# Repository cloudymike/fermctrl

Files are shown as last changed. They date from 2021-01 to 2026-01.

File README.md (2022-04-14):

# TempCtrl
Fermentation temperature controller

# Submodules
This repo includes submodules. After you have cloned, run:
`git submodule init`

# Install micropython on board
`cd tools
./reload.sh
`

# Install software on board

Make sure that you have created a config.py file in gcloudconfig.
If that file is not there, first go to gcloudconfig and follow the instructions
in the README.md file

`cd esp32
./RUN.sh
`

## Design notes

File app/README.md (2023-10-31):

# The app

## Run with flask and mqtt app separate
You need to start both scripts:
* runweb.sh (the flask app)
* runmqtt.sh (the mqtt reader and writer)
* runprometheus.sh (Prometheus colector)

In addition a redis server and a mosquitto server needs to run on localhost

## Run with docker compose

Remove container images that are build. Save some basics like redis and base python
`dockerclean.sh`

Bring up docker environment with a rebuild. Note that you may need to remove images to get a
clean rebuild
`docker-compose up --build`

## Run in testing mode
runtesting.sh

This mode includes a local mosquitto that allows a self contained environment for testing
May be useful as real environment, but some more testing needed.

## Ports
* web server -> 8081 Internal 5000
* prometheus -> 9090
* redis -> Internal  6379
* mosquitto -> 1883

## Prometheus expressions

Find all metrics for a device:
`{device_name=~"testcooler"}   `

Find a metric (actual_temperature) for all devices:
`actual_temperature`

Show just temperatures (actual and target) for one device
`{__name__=~"(actual|target)_temperature", device_name=~"alecooler"} `

To average over time use something like:
`avg_over_time(heater_on{device_name="testcooler"}[10m])`

We are starting to get into hacks here, and a better solution may be to use grafana

## Basic flask app on app engine.
This is obsolete as GOOGLE stopped their IOT mqtt offering

You may have to login to your google account
`gcloud auth login`

This is the google tutorial:
https://cloud.google.com/appengine/docs/standard/python3/quickstart

This is a very useful companion page that lists the gcloud commands that are useful to set things up:
https://medium.com/@dmahugh_70618/deploying-a-flask-app-to-google-app-engine-faa883b5ffab

### Setup service account credentials
export GOOGLE_APPLICATION_CREDENTIALS=~/secrets/gcloud/myproject.json
See https://cloud.google.com/pubsub/docs/building-pubsub-messaging-system#create_service_account_credentials

### Remove projects is a bad thing
They will be in delete mode for 30 days so during that time you can not add other projects. To see what you have in delete mode:

gcloud projects list --filter='lifecycleState:DELETE_REQUESTED'

### Read the logs of a appengine
gcloud app logs tail --project phrasal-talon-439

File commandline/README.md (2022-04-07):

# Commandline to control device

Source setup.sh  to setup virtual environment and include required packages.
Then run each file as a command

## Setup service account credentials
export GOOGLE_APPLICATION_CREDENTIALS=~/secrets/gcloud/myproject.json
See https://cloud.google.com/pubsub/docs/building-pubsub-messaging-system#create_service_account_credentials

## Initial command line with python

### command.py
Will send a command to the device. Currently the only command is the temperature to set.
Example:
```
./command.py 68
```

### subscribe.py
Will get all metrics from device, and try to clean queue
```
# ./subscriber.py
Listening for messages on projects/tempctrlproj/subscriptions/ferm1topic..

Received Message {
  data: b'{"temperature":80.6}'
  ordering_key: ''
  attributes: {
    "deviceId": "esp32tempctrl",
    "deviceNumId": "2577321808646966",
    "deviceRegistryId": "tempctrl",
    "deviceRegistryLocation": "us-central1",
    "projectId": "tempctrlproj",
    "subFolder": ""
  }
}.
```

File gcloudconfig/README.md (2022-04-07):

# Setting up gcloud

## Login
Start with logging in to your account
`gcloud auth login`

This will open a browser to login to your account.

After the login try to run a gcloud command, as example try to check the projects:
`gcloud projects list`

## Variables
Copy the variables.example.sh to variables.sh and update with the values
that matches your setup. If you are starting from scratch, you can probably use variables as
is. If you already have a project started use that project_id. To check if you have a project run
the command:
`gcloud projects list`

## Create a project
If you do not have a ready to go project create this next. Right now we create an app for each project, the
URL is
`https://PROJECT_ID.appspot.com`

Creating a lot of new project id's is a bad things as it takes 30 days to remove them.

To create project use
`./create_project.sh`

To delete a project (though it will take 30 days to happen..):
`./delete_project.sh`

# Create an app
Currently the app is a simple creation of one app per project. Use the following command:
`./create_app.sh`
To delete an app:
`./delete_app.sh`

# Create a device
This setups device and device registry with key and creates a config file that will be used
by app and esp32 board. Among other things this will generate the keypair to be  used
by mqtt to allow esp32 board and google app to communicate.

To create device use
`./create_device.sh`

To delete device use
`./delete_device.sh`

Note that this script also creates topics and subscriptions. These are kind of the same thing in mqtt but
not in gcloud. Note that a subscription expire after EXPIRATION_PERIOD, set to max 365 days.

# config.py
You should now have a file config.py. This file will NOT be checked in with the repo, so you may want to copy
it to a safe place. This file will be used by both app engine build and esp32 build to
link the two together.

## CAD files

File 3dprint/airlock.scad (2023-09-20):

$fa = 1;
$fs = 0.4;


boxdepth = 10;
boxwidth = 22.5;
wallthickness = 1;
ringheight = 6;
braceoffset = 16;
tubediameter = 11;

module lid() {
  difference () {
    cube([boxwidth-2*wallthickness,boxdepth-1*wallthickness,2],center=true);
    translate([0,boxdepth/2-3.5,1]) cube([20.5,1.5,1],center=true); // slot
    translate([0,-boxdepth/2,0]) cube([boxwidth-2*wallthickness,7*wallthickness,2],center=true); //space for bow
  }
}

module topbox(
  boxwidth=boxwidth,
  boxdepth=boxdepth,
  wallthickness=wallthickness,
  tbheight = 17
  ) {
  difference () {
    cube([boxwidth,boxdepth,tbheight],center=true);
    translate([0,-1,6]) cube([boxwidth-2*wallthickness,boxdepth,10],center=true);
    cube([boxwidth-2*wallthickness,boxdepth-2*wallthickness,tbheight],center=true);
  }  
}
module cardslot (boxwidth=boxwidth,boxdepth=boxdepth,wallthickness=wallthickness, csheight=8) {
  difference () {
    cube([boxwidth,boxdepth,csheight],center=true);
    translate([0,boxdepth/2-3.5,0]) cube([boxwidth-2*wallthickness,1.5,csheight],center=true);
    cube([10,boxdepth-2*wallthickness,csheight],center=true);
  }  
}  

module compressionring(ringheight=ringheight,tubediam=11,ringwall=2) {
  difference() {
    cylinder(h=ringheight,d=tubediam+2*ringwall,center=true);
    cylinder(h=ringheight,d=tubediam,center=true);
    translate([0,-ringheight,0]) cube([1,3,ringheight],center=true);
    
  }
}


module prism(l, w, h) {
       polyhedron(points=[
               [0,0,h],           // 0    front top corner
               [-w,0,0],[w,0,0],   // 1, 2 front left & right bottom corners
               [0,l,h],           // 3    back top corner
               [-w,l,0],[w,l,0]    // 4, 5 back left & right bottom corners
       ], faces=[ // points for all faces must be ordered clockwise when looking in
               [0,2,1],    // top face
               [3,4,5],    // base face
               [0,1,4,3],  // h face
               [1,2,5,4],  // w face
               [0,3,5,2],  // hypotenuse face
       ]);
}

module bottombox(
  boxwidth=boxwidth,
  boxdepth=boxdepth,
  wallthickness=wallthickness,
  ringheight = ringheight, 
  braceoffset=braceoffset, 
  tubediam=tubediameter, 
  ringwall=2, 
  bboxh=13
  ) {
  
  difference () {
    cube([boxwidth,boxdepth,bboxh],center=true);
    cube([boxwidth-2*wallthickness,boxdepth-2*wallthickness,13],center=true);
    //Create a notch for the cable connector
    translate([0,-boxdepth/2+wallthickness,0]) cube([10,wallthickness,bboxh],center=true);
  }
  difference () {
    translate([0,-boxdepth/2,-bboxh/2]) rotate([90,0,0]) prism(ringheight, boxwidth/2, braceoffset*2);
    translate([0,-boxdepth/2-braceoffset,-bboxh/2]) cylinder(d=tubediam + ringwall*2, h=ringheight);
    // This is a little hackish, wanted to make the brace a little wider so needed to make it longer and cut off the tip
    translate([0,-boxdepth/2-braceoffset-tubediam,-bboxh/2+ringheight/2]) cube([braceoffset,braceoffset,ringheight],center=true);
  }
  translate([0,-boxdepth/2-braceoffset,-bboxh/2+ringheight/2]) compressionring(ringheight,tubediam,ringwall);
}

module sensorbox(
  boxwidth = boxwidth,
  boxdepth = boxdepth,
  wallthickness = wallthickness,
  ringheight = ringheight, 
  braceoffset=braceoffset, 
  tubediam=tubediameter, 
  ringwall=2
  ) {
    bboxh=13;
    csheight=8;
    tbheight = 18;
    bottombox(boxwidth,boxdepth,wallthickness,ringheight, braceoffset, tubediam, ringwall, bboxh);
    translate([0,0,bboxh/2+csheight/2]) cardslot(boxwidth,boxdepth,wallthickness,csheight);
    translate([0,0,bboxh/2+csheight+tbheight/2]) topbox(boxwidth,boxdepth,wallthickness,tbheight);
}
//bottombox();
//topbox();  
//cardslot(); 

sensorbox();
translate ([40,0,0])  lid();

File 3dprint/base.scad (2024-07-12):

use <scadexamples/electrocookie/baseplate.scad>
baseplate(
    board_version="full",
    bottom_holes=[19,20,21,24,25,26,40,42,61,63],
    top_holes=[40,42,58,60],
    power_connector=true
);

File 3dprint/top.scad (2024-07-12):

use <scadexamples/electrocookie/topbox.scad>
topbox(
    board_version="full",
    display_pin1_row = 23,
    jack_pin1_row = 0,
    ESP32_pin1_column = "B",
    power_connector=true
    );

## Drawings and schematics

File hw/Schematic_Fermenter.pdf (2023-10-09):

A | A

1

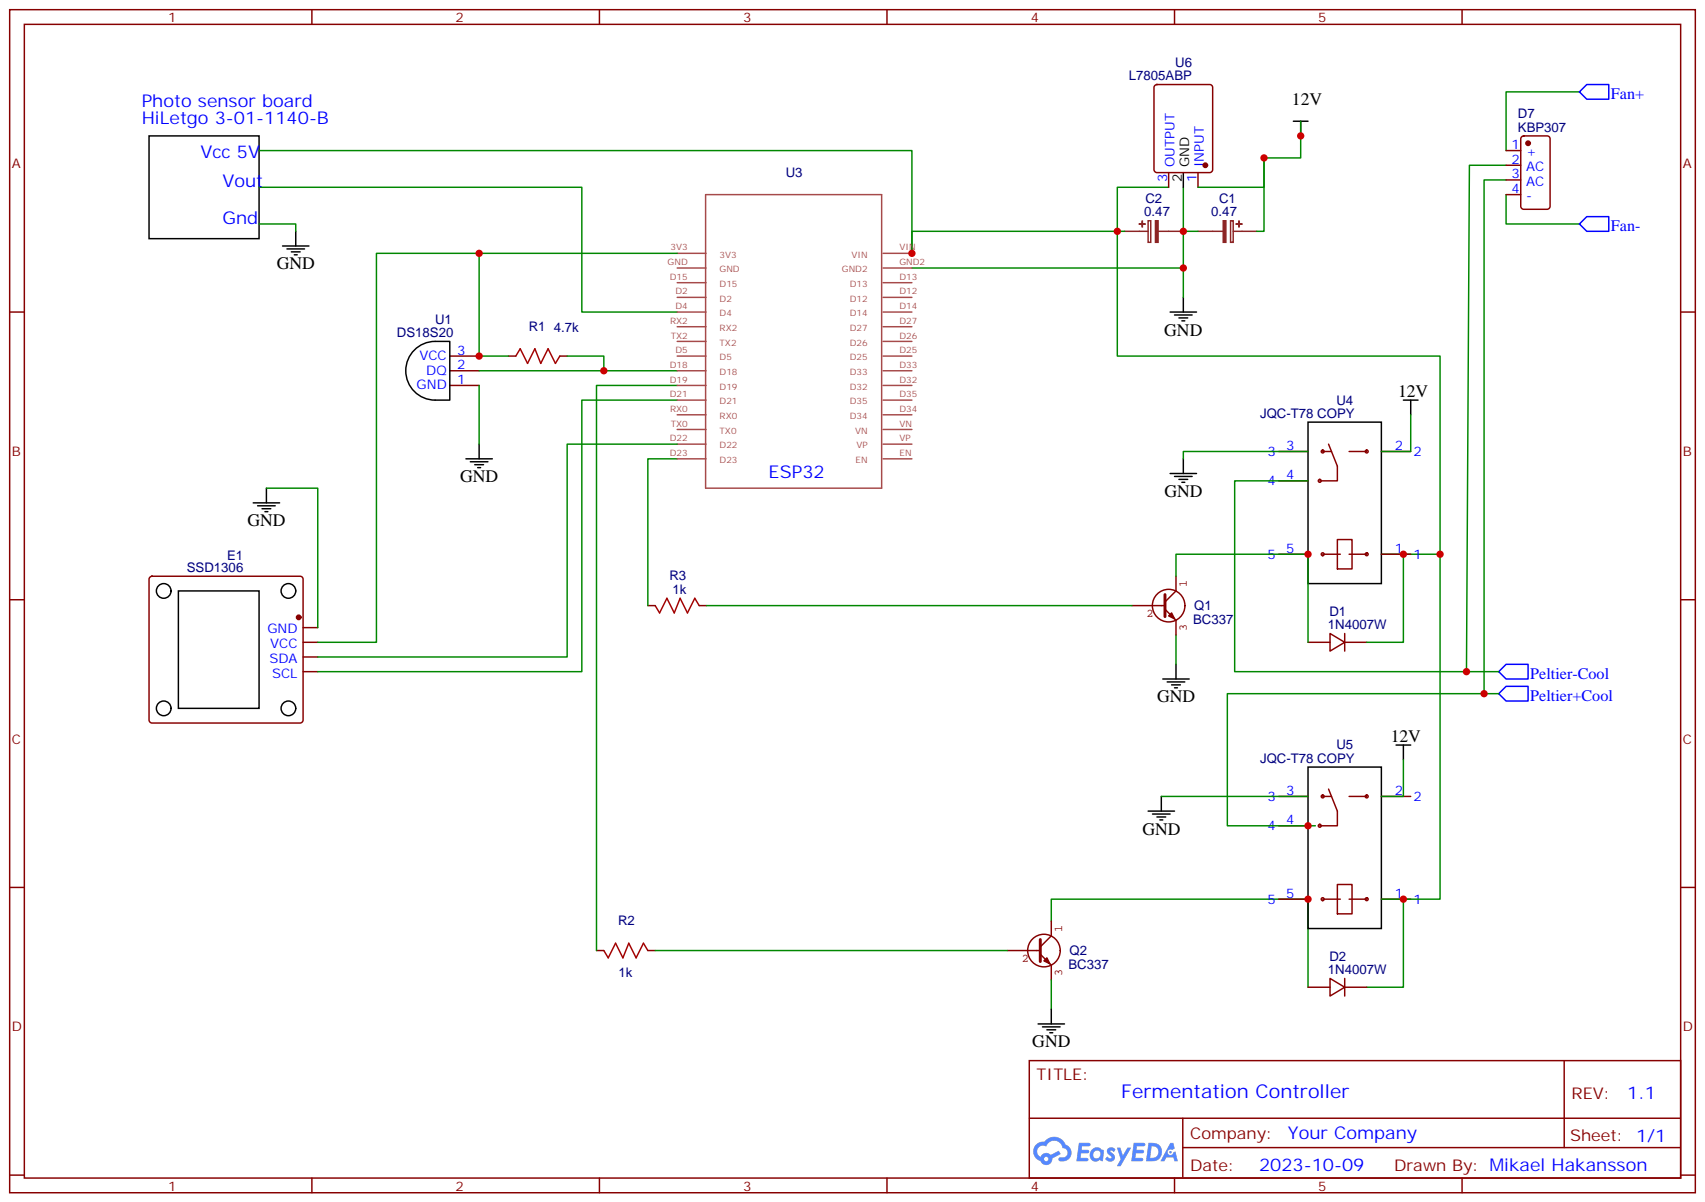
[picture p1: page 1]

Drawn By: Mikael Hakansson

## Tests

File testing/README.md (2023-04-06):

#Testing

Includes files for testing setup in different
environments. Initially setup to test all local host based

## mqtt esp emulator
`mockesp.sh`

Reads the mqtt queue for setting and writes a random number as temperature.

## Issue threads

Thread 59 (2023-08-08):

reset day today

cloudymike, 2023-08-08:
The current day should be easily set to, at least, 0 so we can restart the program. Could be a command start of restart.
As an alternative set the actual day but think this will be more confusing

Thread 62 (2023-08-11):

Add Redis

cloudymike, 2023-08-11:
Do not change any of the code just replace the global variable with reading data from redis
Variable name should be namespace:variable, but intially skip or use dummy namespace like fermctrl:TEMPERATURE
Later we should namespace by project,device. Note that the "namespace" for mqtt uses paths,and '/' so not suitable for Redis.

Closed 2023-08-13.

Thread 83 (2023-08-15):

multi device

cloudymike, 2023-08-15:
Enable multi device usage

- Select device currently managed/viewed
- Create header to show current device
- Create a list of devices by looking at what mqtt paths are under fermctrl (or whatever toplevel is in use)
- list to be stored in REDIS and updated with some frequency

cloudymike, 2023-08-18:
See #82

Closed 2023-08-18.

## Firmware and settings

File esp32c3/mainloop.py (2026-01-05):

# Complete project details at https://RandomNerdTutorials.com

import time
import machine
import ntptime
import json
#import wlan
import tempreader
import internaltempreader
import relay
#import mqtt_local
import LED
import textout
import bignumber
import savestate
import config
import esp32
import uasyncio as asyncio

VERSION=0.7

# enable watchdog with a timeout of 5min
# Keep a long timeout so you can reload software before timeout
wdt = machine.WDT(timeout=300000)

# Sense a switch. Add pull up to allow design without switch installed
offonswitch = machine.Pin(21, machine.Pin.IN, machine.Pin.PULL_UP)

#===================== Bubble counter 
BubbleCount = 0
LastBubbleMs = 0

def bubble_interrupt(pin):
    global BubbleCount
    global LastBubbleMs
    global interrupt_pin
    interrupt_pin = pin

    BubbleCount = BubbleCount + 1
    print("There is a bubble....oooooOOOOO ")

def get_bubblecount():
    global BubbleCount
    bubblecount = BubbleCount
    BubbleCount = 0
    return(bubblecount)


#pir = machine.Pin(4, machine.Pin.IN)
#pir.irq(trigger=machine.Pin.IRQ_RISING, handler=bubble_interrupt)

#===================== Bubble counter end

class mainloop:
    def __init__(self):
        self.rtc = machine.RTC()

        self.txt = textout.textout()
        self.txt.text('Starting....')

        try:
            ntptime.settime()
        except:
            pass
            #Use old timegcloud

        self.unit='F'
        self.temprange=0.1   # Range to hold the temperature in, +/-
        self.hysterisis=0.2 # On off difference, to avoid toggling
        self.temp=0.0
        self.bubblecount = 0
        self.cool = 0
        self.heat = 0
        self.publish_json={}

        self.tempDevice = tempreader.tempreader(self.unit)

        try:
            dummy=self.tempDevice.get_temp()
        except:
            self.tempDevice = internaltempreader.internaltempreader(self.unit)
        self.profile = {'0':0}
        self.dryhop1 = 0
        self.lastmessage = ""
        self.message = ""



        self.state = savestate.readState()
        try:
            self.target = self.state['target']
        except:
            self.target = 0.0
        try:
            self.profile = self.state['profile']
        except:
            self.profile = {'0':0}
        try:
            self.dryhop1 = self.state['dryhop1']
        except:
            self.dryhop1 = 0
        try:
            self.start_epoch = self.state['start_epoch']
        except:
            self.start_epoch = time.time()

        # for debugging
        #self.start_epoch = time.time() + 3*86400

        # Rebuild the state with current values
        # Creates a clean file for the future
        self.writeStateFile()


        #self.m = mqtt_local.MQTTlocal(config.device_name, config.hostname, 1883, config.device_topic, config.app_topic)

    # Create a proper dict and save as a json file
    def writeStateFile(self):
        self.state = {}
        self.state['target'] = self.target
        self.state['start_epoch'] = self.start_epoch
        self.state['profile'] = self.profile
        self.state['dryhop1'] = self.dryhop1
        savestate.writeState(self.state)


    def thermostat(self):
        self.get_mqttdata()
        self.current_target()
        self.get_temp()
        # Remove for now as ESP32C3 is only working with yeast starter
        '''
        if self.temp > self.target + self.hysterisis + self.temprange:
            relay.COLD.on()
            relay.HOT.off()
            self.heat = 0
            self.cool = 1
        elif self.temp < self.target - self.hysterisis - self.temprange:
            relay.HOT.on()
            relay.COLD.off()
            self.heat = 1
            self.cool = 0
        elif self.temp < self.target + self.temprange and self.temp > self.target - self.temprange:
            relay.COLD.off()
            relay.HOT.off()
            self.heat = 0
            self.cool = 0
        else:
            pass
        '''
        #For yeast starter, relay is backwards
        if self.temp > self.target + self.hysterisis + self.temprange:
            relay.HOT.value(1)
            self.heat = 0
            self.cool = 0
        elif self.temp < self.target - self.hysterisis - self.temprange:
            relay.HOT.value(0)
            self.heat = 1
            self.cool = 0
        elif self.temp < self.target + self.temprange and self.temp > self.target - self.temprange:
            relay.HOT.value(1)
            self.heat = 0
            self.cool = 0
        else:
            pass
    def setMessage(self,message):
        self.message = message
        print(message)

    def current_target(self):
        day,hour,min,second = self.run_time()
        self.target = self.profile['0']

        sorted_keys = sorted(self.profile, key=int)
        for key_day in sorted_keys:
            if int(key_day) > day:
                break;
            self.target = float(self.profile[key_day])
        #print("Today {}, using  temp {} in profile {}".format(day,self.target,self.profile))


    def get_mqttdata(self):
        targetstring = self.message
        print("Message:{}".format(self.message))
        if targetstring != self.lastmessage:
            self.lastmessage=targetstring
            try:
                full_profile = json.loads(targetstring)
                temperatures_profile = full_profile['temperatures']
                print('Got new target:{}'.format(full_profile))
                print('Old target:{}'.format(self.profile))
                update=False
                if full_profile['dryhop1'] != self.dryhop1:
                    update=True
                    self.dryhop1 = full_profile['dryhop1']
                if temperatures_profile != self.profile:
                    update = True
                    self.profile = temperatures_profile
                if update:
                    self.start_epoch = time.time()
                    self.writeStateFile()
            except:
                pass
                #print("Recieved unrecognized mqttdata")

        return()


    def get_temp(self):
        self.temp = self.tempDevice.get_temp()
        return(self.temp)


    def run_time(self):
        current_secs = time.time() - self.start_epoch
        year,month,day,hour,min,second,dummy1,dummy2 = time.localtime(current_secs)
        day = day - 1
        if month == 2:
            day = day + 31
        return((day,hour,min,second))

    def display_detail(self):
        day,hour,min,second = self.run_time()
        time_str = "Day {}".format(day)
        self.txt.clear()
        #self.txt.centerline(self.profile,1)
        self.txt.centerline(time_str,3)

        self.txt.centerline("Temp: {:.1f}{}".format(self.temp,self.unit),4)
        self.txt.centerline("Target: {}".format(self.target),5)
        self.txt.show()

    def display_simple(self):
        self.txt.clear()
        day,hour,min,second = self.run_time()
        #self.txt.centerline("Day:{}      Tgt:{}".format(day,self.target),1)
        self.txt.leftline("Day:{}".format(day),1)
        self.txt.rightline("Tgt:{}".format(self.target),1)
        bignumber.bigTemp(self.txt.display(), self.temp, self.unit)

    def show_off(self):
        org_y = 20
        width = 30
        self.txt.clear()
        oled=self.txt.display()
        if oled:
            bignumber.bigDigit( oled,20, org_y, 0)
            bignumber.bigLetter(oled,50,org_y,'F')
            bignumber.bigLetter(oled,80,org_y,'F')
            oled.show()
        else:
            print("OFF")

    def everything_off(self):
        relay.COLD.off()
        relay.HOT.off()
        relay.dryhop1.off()


    def currentStatus(self):
        data = bytes(json.dumps(self.publish_json), 'utf-8')
        return(data)

    # Just check once a day for this
    # Need to not dryhop for day 0. Leave this out for testing.
    def dryhop1Action(self,day,hour,minute,second):
        if (hour == 0 and minute == 0):
            if second < 10 and day == int(self.dryhop1):
            #if second < 10 and day == int(self.dryhop1) and day > 0:
                relay.dryhop1.value(1)
            else:
                relay.dryhop1.value(0)

    async def run(self):

        old_second = 99
        old_minute = 99
        LEDvalue=0;
        while True:
            await asyncio.sleep_ms(1000)
            #self.display_detail()

            day,hour,minute,second = self.run_time()

            # Cycle over x time
            if second != old_second:
                old_second = second
                # Actions every interval of seconds for C3
                if offonswitch.value():
                    if not (second % 4):
                        self.display_simple()
                        LEDvalue=(LEDvalue+1)%2
                        LED.LED.value(LEDvalue)
                        wdt.feed()

                        self.thermostat()
                        self.dryhop1Action(day,hour,minute,second)

                        publish_json = {}
                        publish_json["temperature"] = self.temp
                        publish_json["bubblecount"] = self.bubblecount
                        publish_json["heat"] = self.heat
                        publish_json["cool"] = self.cool
                        publish_json["target"] = self.target
                        publish_json["day"] = day
                        publish_json["dryhop1"] = self.dryhop1
                        publish_json["profile"] = self.profile
                        #print("Publishing: {}".format(publish_json))
                        self.publish_json=publish_json
                        self.writeStateFile()
                        #print(day,hour,minute,second)
                        #print(LEDvalue)
                else:
                    self.everything_off();
                    self.show_off();
 
            if minute != old_minute:
                old_minute = minute
                self.bubblecount = get_bubblecount()

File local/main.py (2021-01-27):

# Complete project details at https://RandomNerdTutorials.com

import textout
import time
import machine
import ntptime
import wlan
import tempreader
import relay

#import awsiotconfig
#from mqtt_reader_aws import MQTTReaderAWS

import mqtthost
from mqtt_reader import MQTTReader


class mainloop:
    def __init__(self):
        wlan.do_connect()
        self.rtc = machine.RTC()

        try:
            ntptime.settime()
        except:
            pass
            #Use old time

        self.unit='F'
        self.hysterisis=0.5
        self.temp=0.0
        self.target = 0.0
        self.tempDevice = tempreader.tempreader(self.unit)

        self.m = MQTTReader(
            mqtthost.MQTT_CLIENT_ID,
            mqtthost.MQTT_HOST,
            mqtthost.MQTT_PORT,
            mqtthost.MQTT_TOPIC)

        self.txt = textout.textout()

    def thermostat(self):
        self.get_target()
        self.get_temp()
        if self.temp > self.target + self.hysterisis:
            relay.COLD.on()
            relay.HOT.off()
        elif self.temp < self.target - self.hysterisis :
            relay.HOT.on()
            relay.COLD.off()
        else:
            relay.COLD.off()
            relay.HOT.off()

    def get_target(self):
        targetstring = self.m.last_msg()
        try:
            self.target = float(targetstring)
        except:
            print("ERROR: No valid target")
        return(self.target)

    def get_temp(self):
        self.temp = self.tempDevice.get_temp()
        return(self.temp)

    def run(self):
        old_second = 99
        while True:
            # Check message, if none, keep going
            # If in separate loop, use wait_msg that holds until there is a message
            self.m.check_msg()
            #date_str = "Date: {1:02d}/{2:02d}/{0:4d}".format(*self.rtc.datetime())
            current_time = self.rtc.datetime()
            year,*z,hour,min,second,us=current_time

            # Cycle over x time
            if second != old_second:
                old_second = second
                self.thermostat()
                time_str = "UTC: {4:02d}:{5:02d}:{6:02d}".format(*current_time)
                self.txt.clear()
                self.txt.centerline(time_str,3)

                self.txt.centerline("Temp: {:.1f}{}".format(self.temp,self.unit),4)

                self.txt.centerline("Target: {}".format(self.target),5)
                self.txt.show()


if __name__ == "__main__":
    m = mainloop()
    m.run()

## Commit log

2022-07-03 Save and read profile at reboot
    [main.py]
2022-07-06 Updated esp32
2023-08-18 82 mqtt redis namespace (#89)
    * redis working for new profile
    * Use device name in read loop
    * Added device path to redis but not setting of current device or device list:
2023-08-18 82 redis namespace (#91)
    * device list from configuration
    * Device selector
2023-08-19 93 prometheus (#95)
    * wip
    * working docker prometheus, but prometheus.yaml is currently a hack
    * Proper prometheusconfig for docker
    * Added prometheus configs for local
2023-08-19 Preload form with right radio button (#96)
2023-08-19 94 metric go through all devices in loop (#98)
    * Use prometheus client to do cleaner metric
    * Comment updates
    * Update readme
2023-08-20 Fixed bad trimmming (#99)
    [main.py]
2023-08-23 81 dockerized mqtt (#101)
    * WIP, mounts are local and changes ownership. Create DOCKERFILE to add config,skip persistent mounts
    * Config file baked in
    * Working mosquitto container for testing purpose,started with separate docker-compose
2023-09-12 Flex docker compose (#102)
    * still used config values in places
    * Updated runtesting as well
    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
    [main.py]
2023-09-19 initialworking (#109)
    [airlock.scad]
2023-09-19 Schematics (#107)
2023-09-19 Bubblecounter (#108)
    * ESP32 working with counter
    * bubblecount working in basic check
    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
2023-09-20 Shorter lid (#110)
    * Short lid
    * Lid not blocking airlock
    [airlock.scad]
2023-09-30 Grafana (#111)
    * WIP, added provisioner for prometheus and one specific dashboard, testctrl
    * Update days of fermentation every minute, so we do not have to wait too long, was 1h
    * Working variable (var-device=testcooler)
    * Better UID for dashboard
    * Better uid for datasource prometheus
    * copypasta, two templating sections
    * Allow anonymous access to dashboards for view
    * Create embedded graph in webapp
    * Cleanup
    * Lower refresh interval to 1 min
    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
    [main.py]
2023-10-09 Updated schematics (#112)
2023-10-31 Heatcool (#117)
    * Basic working on esp32 and in app
    * Graph average time heater or cooler is on
2023-11-02 Profile from device (#119)
    * Make sure profile is read from device
    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
2023-11-03 Finish day (#120)
    * Better port handling
    * Get profile from device if not to be updated
    * Displaying number of days
    * Add finishday to metric
    * save by device
    * No days in grafana
    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
2023-12-20 Use button instead of tab (#132)
2024-01-13 Added holes to base (#135)
    [base.scad]
2024-03-31 OK sending data (#144)
    * OK sending data
    * dryhop1 as a variable on esp32
    * Allowing dryhop1 to control something
2024-07-09 Added hole for winch power (#145)
    [base.scad]
2024-07-12 Sideconnector (#146)
    * updated submodule
    * Use side connector
    [base.scad, top.scad]
2025-02-08 Beersmithname (#147)
    * initial
    * Add pull from beersmith
    * working load of temperatures
2025-08-28 Littecleanup (#152)
    * Device cleanup
    * remove base
    * Helpers to use parameters
    * Brokeout helpers
    [main.py]
2025-11-18 Slow down for esp32C3 (#158)
2025-11-24 Comment out interrupt for bubble count as it killed the device w/o actual pin used (#161)
2025-12-12 Added switch. Default without switch but resistor is on (#162)
2026-01-05 Yeaststarterheatswap (#164)
    * fixPowerSwap
    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
    [mainloop.py]
2026-11-05 Add print of network config (#166)
